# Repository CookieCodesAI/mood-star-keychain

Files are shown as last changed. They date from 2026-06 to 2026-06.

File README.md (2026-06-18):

# Mood Star Keychain
A cute and aesthetic star keychain that allows you to communicate your mood to your friends!

## THIS PROJECT IS IN PROGRESS

## Features
- 4 Neopixels to allow for aesthetic lighting
- WiFi based communication with friends
- USB C port for easy power and programming

### Schematic
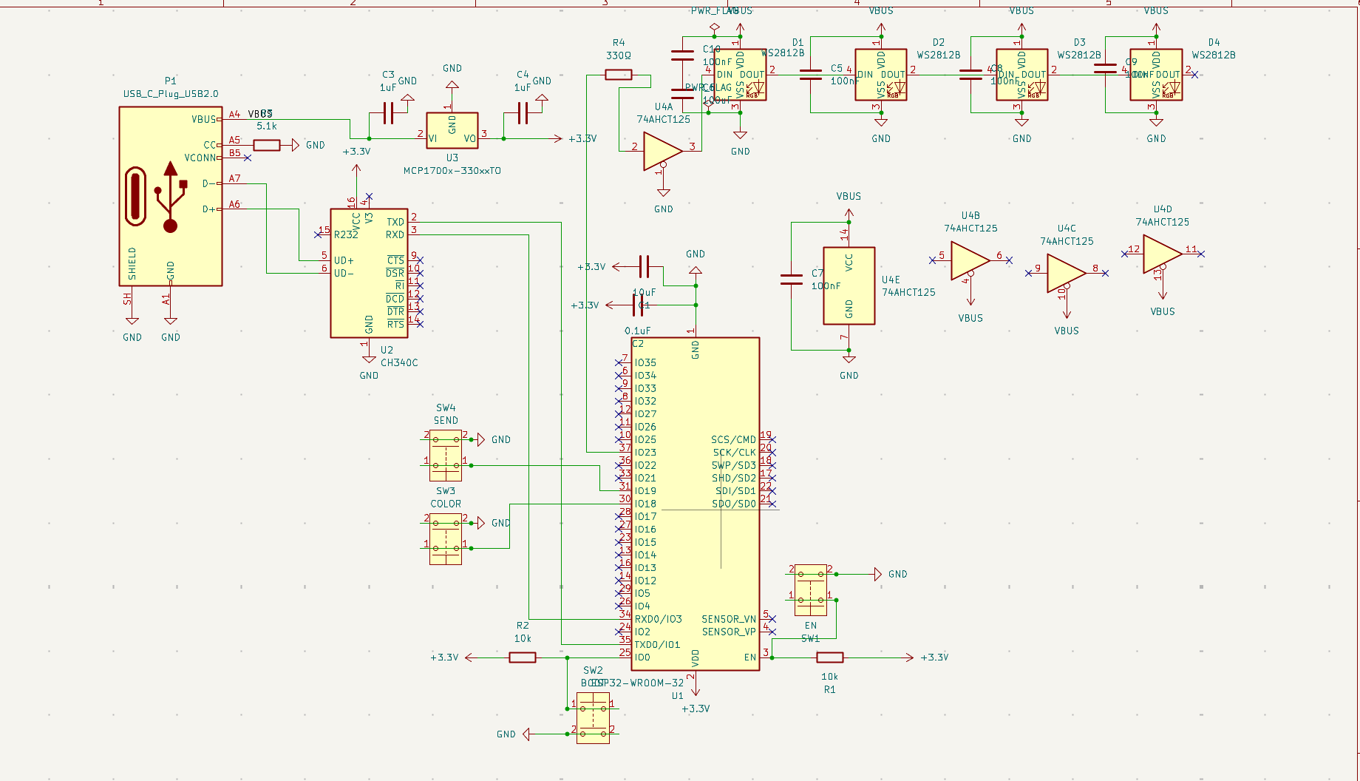
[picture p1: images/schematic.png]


### PCB
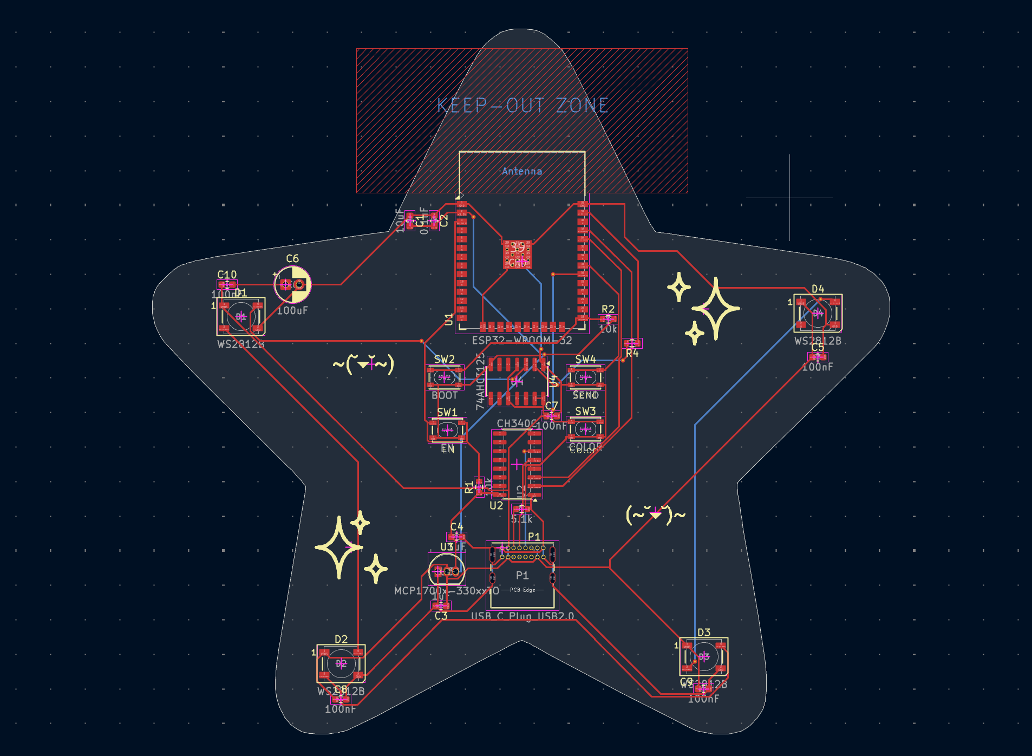
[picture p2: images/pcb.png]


### 3dmodel
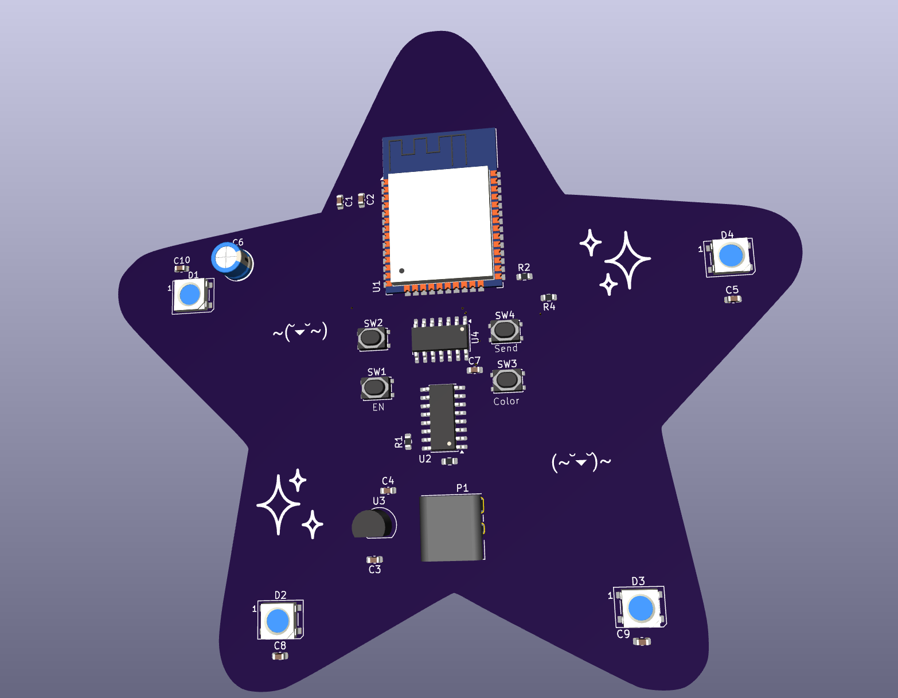
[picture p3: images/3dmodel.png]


### Next steps:
- Get PCB board and componenets and solder everything
- Edit firmware in accordance to the Neopixels added
- Aestheticize using pipe cleaners

### BOM
| Index | LCSC# | MPN | Manufacturer | Package | Customer # | Description | RoHS | Quantity | MOQ | Multiple | Unit Price($) | Extended Price($) | Product Link |
|---|---|---|---|---|---|---|---|---|-----|---|---|---|---|
| 1 | C19702 | CL10A106KP8NNNC | Samsung Electro-Mechanics | 603 | | 10uF ±10% 10V Ceramic Capacitor X5R 0603 | yes  | 20 | 20  | 20 | 0.0265 | 0.53 | https://www.lcsc.com/product-detail/C19702.html |
| 2 | C14663 | CC0603KRX7R9BB104 | YAGEO | 603 | | 100nF ±10% 50V Ceramic Capacitor X7R 0603 | yes  | 100 | 100 | 100 | 0.0172 | 1.72 | https://www.lcsc.com/product-detail/C14663.html |
| 3 | C15849 | CL10A105KB8NNNC | Samsung Electro-Mechanics | 603 | | 1uF ±10% 50V Ceramic Capacitor X5R 0603 | yes  | 50 | 50  | 50 | 0.0148 | 0.74 | https://www.lcsc.com/product-detail/C15849.html |
| 4 | C49256785 | ERA10V100M5X7 | JIERR | Through Hole,D5xL7mm | | 100uF 10V Aluminum Electrolytic Capacitors Through Hole,D5xL7mm 2000hrs@105℃ | yes  | 20 | 20  | 20 | 0.0246 | 0.49 | https://www.lcsc.com/product-detail/C49256785.html |
| 5 | C2761795  | WS2812B-B/T | Worldsemi | SMD5050-4P | | SMD5050-4P LED Addressable, Specialty RoHS | yes  | 10 | 5 | 5 | 0.1072 | 1.07 | https://www.lcsc.com/product-detail/C2761795.html  |
| 6 | C25804 | 0603WAF1002T5E | UNI-ROYAL | 603 | | 10kΩ ±1% 100mW 0603 Thick Film Resistor | yes  | 100 | 100 | 100 | 0.0012 | 0.12 | https://www.lcsc.com/product-detail/C25804.html |
| 7 | C23186 | 0603WAF5101T5E | UNI-ROYAL | 603 | | 5.1kΩ ±1% 100mW 0603 Thick Film Resistor | yes  | 100 | 100 | 100 | 0.0018 | 0.18 | https://www.lcsc.com/product-detail/C23186.html |
| 8 | C23138 | 0603WAF3300T5E | UNI-ROYAL | 603 | | 330Ω ±1% 100mW 0603 Thick Film Resistor | yes  | 100 | 100 | 100 | 0.0016 | 0.16 | https://www.lcsc.com/product-detail/C23138.html |
| 9 | C116501 | PTS810SJM250SMTRLFS | C&K | SMD-4P,4.2x3.2mm | | Tactile Switch SPST 160gf 2.5mm J-Lead 4.2mm x 3.2mm Surface Mount | yes  | 8 | 1 | 1 | 0.5771 | 4.62 | https://www.lcsc.com/product-detail/C116501.html |
| 10 | C82899 | ESP32-WROOM-32-N4 | ESPRESSIF | SMD,25.5x18mm | | 2.4GHz ESP32-DOWDQ6 -98dBm SMD,25.5x18mm RF Transceiver Modules and Modems RoHS | yes  | 2 | 1 | 1 | 4.3259 | 8.65 | https://www.lcsc.com/product-detail/C82899.html |
| 11 | C84681 | CH340C | WCH | SOP-16 | | Transceiver 2Mbps USB 2.0 SOP-16 Interface Controllers RoHS | yes  | 2 | 1 | 1 | 0.5863 | 1.17 | https://www.lcsc.com/product-detail/C84681.html |
| 12 | C511277 | MCP1700-3302E/TO | MICROCHIP | TO-92-3 | | 3.3V Positive Fixed TO-92-3 Voltage Regulators - Linear, Low Drop Out (LDO) Regulators RoHS | yes  | 2 | 1 | 1 | 0.803 | 1.61 | https://www.lcsc.com/product-detail/C511277.html |
| 13 | C155176 | SN74AHCT125DR | TI | SOIC-14 | | 4.5V~5.5V 1 4 20uA 7.5ns@5V,50pF SOIC-14 Buffers, Drivers, Receivers, Transceivers RoHS | yes  | 2 | 1 | 1 | 0.3503 | 0.7 | https://www.lcsc.com/product-detail/C155176.html |
| 14 | C7095263  | USB4085-GF-A | Global Connector Technology | Through Hole | | USB 2.0 5A 1 -40℃~+85℃ Right Angle Through Hole USB, DVI, HDMI Connector Assemblies RoHS | yes  | 2 | 1 | 1 | 1.4228 | 2.85 | https://www.lcsc.com/product-detail/C7095263.html  |
| 15 | | | JLCPCB | | | PCB | | 5 | 5 | | | $8.40 | |
| | | | | | | | | | | | | | |
| TOTAL (Without Shipping) | $33.01 | | | | | | | | | | | | |
| TOTAL (With Shipping) | $71.42 | | | | | | | | | | | | |
### Timelapses 
- [1: Starting Out](https://lapse.hackclub.com/timelapse/5bXvsicgwVzP)
- [2: Basic Firmware](https://lapse.hackclub.com/timelapse/i8mPg4Ti3nzj)
- [3: Schematic](https://lapse.hackclub.com/timelapse/T4jO5MK8scFe)
- [4: General PCB](https://lapse.hackclub.com/timelapse/qJWxwG7Hxz8r)
- [5: Finalized PCB](https://lapse.hackclub.com/timelapse/edrZpXVRfG2W)
- [6: Manufacturing](https://lapse.hackclub.com/timelapse/CAW8ewQiKnNG)

### Libraries needed
umqttsimple.py: https://raw.githubusercontent.com/RuiSantosdotme/ESP-MicroPython/master/code/MQTT/umqttsimple.py

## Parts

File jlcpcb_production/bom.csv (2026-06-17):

Designator | Footprint | Quantity | Value | LCSC Part #
C1 | 0603 | 1 | 10uF
C10, C5, C7, C8, C9 | 0603 | 5 | 100nF
C2 | 0603 | 1 | 0.1uF
C3, C4 | 0603 | 2 | 1uF
C6 | CP_Radial_D5.0mm_P2.00mm | 1 | 100uF
D1, D2, D3, D4 | LED_WS2812B_PLCC4_5.0x5.0mm_P3.2mm | 4 | WS2812B
P1 | USB_C_Receptacle_GCT_USB4085 | 1 | USB_C_Plug_USB2.0
R1, R2 | 0603 | 2 | 10k
R3 | 0603 | 1 | 5.1k
R4 | 0603 | 1 | 330Ω
SW1 | SW_SPST_PTS810 | 1 | EN
SW2 | SW_SPST_PTS810 | 1 | BOOT
SW3 | SW_SPST_PTS810 | 1 | COLOR
SW4 | SW_SPST_PTS810 | 1 | SEND
U1 | ESP32-WROOM-32 | 1 | ESP32-WROOM-32
U2 | SOIC-16_3.9x9.9mm_P1.27mm | 1 | CH340C
U3 | TO-92_Inline | 1 | MCP1700x-330xxTO
U4 | SOIC-14_3.9x8.7mm_P1.27mm | 1 | 74AHCT125

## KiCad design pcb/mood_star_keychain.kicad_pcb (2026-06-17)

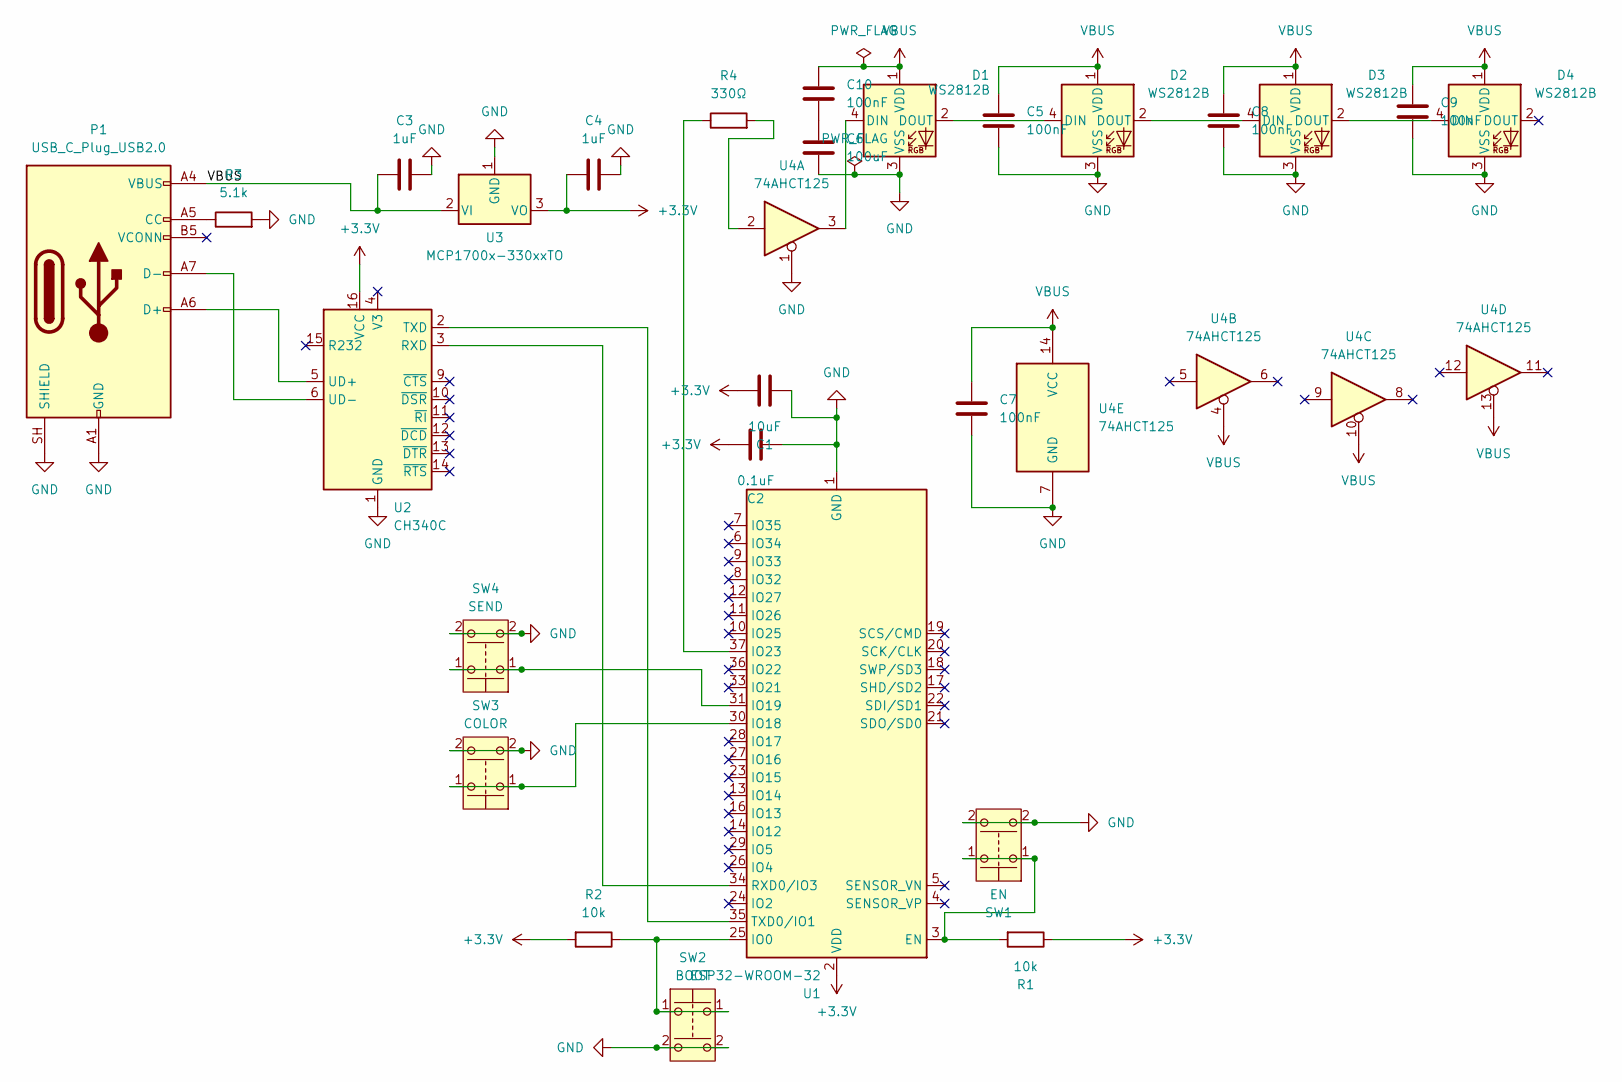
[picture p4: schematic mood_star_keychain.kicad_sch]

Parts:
C1: 10uF; C_0603_1608Metric
C2: 0.1uF; C_0603_1608Metric
C3, C4: 1uF; C_0603_1608Metric
C5, C7, C8, C9, C10: 100nF; C_0603_1608Metric
C6: 100uF; CP_Radial_D5.0mm_P2.00mm
D1, D2, D3, D4: WS2812B; LED_WS2812B_PLCC4_5.0x5.0mm_P3.2mm
P1: USB_C_Plug_USB2.0; USB_C_Receptacle_GCT_USB4085
R1, R2: 10k; R_0603_1608Metric
R3: 5.1k; R_0603_1608Metric
R4: 330Ω; R_0603_1608Metric
SW1: EN; SW_SPST_PTS810
SW2: BOOT; SW_SPST_PTS810
SW3: COLOR; SW_SPST_PTS810
SW4: SEND; SW_SPST_PTS810
U1: ESP32-WROOM-32
U2: CH340C; SOIC-16_3.9x9.9mm_P1.27mm
U3: MCP1700x-330xxTO; TO-92_Inline
U4: 74AHCT125; SOIC-14_3.9x8.7mm_P1.27mm

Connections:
+3.3V: C1.2, C2.2, C4.1, R1.1, R2.2, U1.2 (VDD), U2.16 (VCC), U3.3 (VO)
GND: C1.1, C2.1, C3.2, C4.2, C5.2, C6.2, C7.2, C8.2, C9.2, D1.3 (VSS), D2.3 (VSS), D3.3 (VSS), D4.3 (VSS), P1.A1 (GND), P1.A12 (GND), P1.B1 (GND), P1.B12 (GND), P1.SH (SHIELD), R3.2, SW1.2 (3), SW2.2 (3), SW3.2 (3), SW4.2 (4), U1.1 (GND), U1.15 (GND), U1.38 (GND), U1.39 (GND), U2.1 (GND), U3.1 (GND), U4.1, U4.7 (GND)
unnamed: C6.1, C10.2
unnamed: D1.4 (DIN), U4.3
unnamed: D1.2 (DOUT), D2.4 (DIN)
unnamed: D2.2 (DOUT), D3.4 (DIN)
unnamed: D3.2 (DOUT), D4.4 (DIN)
unnamed: P1.A5 (CC), R3.1
unnamed: P1.A6 (D+), U2.5 (UD+)
unnamed: P1.A7 (D-), U2.6 (UD-)
unnamed: R4.2, U4.2
unnamed: R1.2, SW1.1, U1.3 (EN)
unnamed: R2.1, SW2.1, U1.25 (IO0)
unnamed: SW3.1, U1.30 (IO18)
unnamed: SW4.1, U1.31 (IO19)
unnamed: R4.1, U1.37 (IO23)
unnamed: U1.34 (RXD0/IO3), U2.3 (RXD)
unnamed: U1.35 (TXD0/IO1), U2.2 (TXD)
VBUS: C3.1, C5.1, C7.1, C8.1, C9.1, C10.1, D1.1 (VDD), D2.1 (VDD), D3.1 (VDD), D4.1 (VDD), P1.A4 (VBUS), P1.A9 (VBUS), P1.B4 (VBUS), P1.B9 (VBUS), U3.2 (VI), U4.4, U4.10, U4.13, U4.14 (VCC)

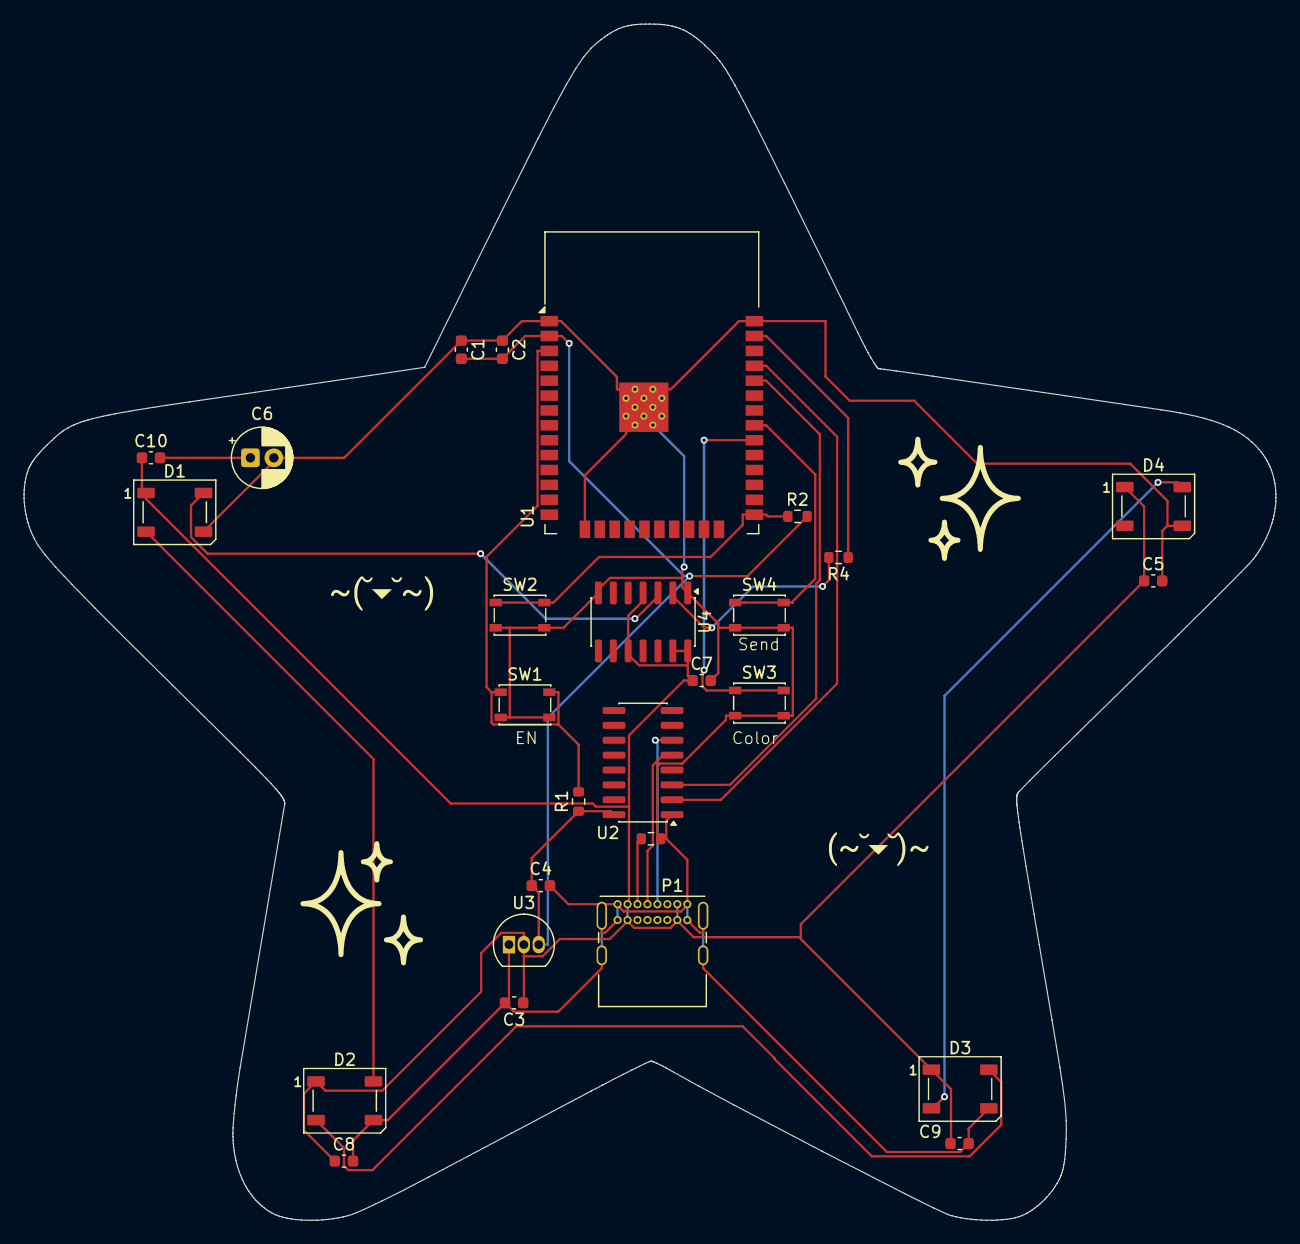
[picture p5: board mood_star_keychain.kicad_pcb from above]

Board: 2 copper layers, 106.8 x 102.1 mm, 30 parts (0 on the bottom side), 19 nets.

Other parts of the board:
F***: LOGO
H***: LOGO
I***: LOGO

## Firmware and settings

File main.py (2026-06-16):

#This is for ESP32 A, for ESP32 B you have to change all the a --> b and all the b --> a in this file
from machine import Pin, PWM
from time import sleep
from umqttsimple import MQTTClient

def callback(topic, msg):
    print("Topic:", topic)
    print("Got the message:", msg)
    global curr 
    curr = int(msg)
    display()
    
broker = "broker.hivemq.com"
client = MQTTClient(
        client_id = "esp32_a",
        server = broker
)
client.connect()
client.set_callback(callback)
client.subscribe(b"esp32/b")



# Color changing code
red = PWM(Pin(23), freq=5000)
green = PWM(Pin(22),freq=5000)
blue = PWM(Pin(21),freq=5000)

color_change = Pin(18, Pin.IN, Pin.PULL_UP)
send = Pin(19, Pin.IN, Pin.PULL_UP)

colors = ["red","yellow","green","cyan","blue", "purple", "pink","white"]
curr = 0

def set_color(r,g,b):
    r_bit = int((r/255)*65535)
    b_bit = int((b/255)*65535)
    g_bit = int((g/255)*65535)
    
    red.duty_u16(r_bit)
    green.duty_u16(g_bit)
    blue.duty_u16(b_bit)
    

def display():
    print(colors[curr])
    if colors[curr] == "red":
        set_color(255,0,0)
    elif colors[curr] == "yellow":
        set_color(255,255,0)
    elif colors[curr] == "green":
        set_color(0,255,0)
    elif colors[curr] == "cyan":
        set_color(0,255,255)
    elif colors[curr] == "blue":
        set_color(0,0,255)
    elif colors[curr] == "pink":
        set_color(255,0,255)
    elif colors[curr] == "white":
        set_color(255,255,255)
    elif colors[curr] == "purple":
        set_color(100, 3, 255)

display()
last_state = 1
while True:
    client.check_msg()
    curr_state = send.value()
    if color_change.value() == 0:
        if (curr == len(colors)-1):
            curr= 0;
        else:
            curr+=1
        display()
    while color_change.value() == 0:
        pass
    if last_state ==1 and curr_state == 0:
        client.publish(b"esp32/a", str(curr))
        print("value was sent: ",  str(curr))
    last_state = curr_state

    

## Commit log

2026-06-15 created readme and basic main.py color switch code
2026-06-16 finished basic firmware and esp32s are communicating properly
2026-06-17 added all kicad files and manufacturing files as well as bom
    [Mood_Star_Keychain_BOM.csv, bom.csv, designators.csv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]
